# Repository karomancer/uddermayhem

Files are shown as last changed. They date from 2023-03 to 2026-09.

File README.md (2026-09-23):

# Udder Mayhem

A rhythm game you play by milking a cow. Squeeze the silicone udder in time with the music to fill coffee cups for the customers of a cow-run café.

Udder Mayhem started as the midterm for *The New Arcade* at NYU ITP in spring 2023, went on to the ITP Showcase and the Coney Island Maker Faire, and was written up in Make Magazine. The full story, with photos and videos, is on my portfolio: https://www.karinachowtime.com/portfolio/uddermayhem

## What's in this repo

| Folder | What it is |
|---|---|
| `teensy/` | Firmware for the udder controller. A Teensy reads four force-sensing resistors, one per teat, and shows up to the computer as a keyboard. |
| `CAD/` | Fusion 360 and STL files for the controller body and the silicone udder mold. |
| `MakeMagazine/` | Files that go with the Make Magazine article, including the one-piece mold box. |
| `BovineBaristaGame/` | The original Unity project from the 2023 class, under the game's working title. This is the hand-written version described in the portfolio write-up. |

## Playing it

**Play the current arcade build in your browser: https://karomancer.github.io/uddermayhem/**

The controller presses plain keyboard keys, so anything that runs the game works with either the udder or a keyboard:

| Teat | Key |
|---|---|
| Back left | Q |
| Back right | W |
| Front left | A |
| Front right | S |

Squeeze when a cup arrives under a teat and let go when it's full.

## The current game

The version people play at events today is a much bigger arcade build that runs on a Raspberry Pi inside the cabinet, made together with Kevin Mitchell. That's the build linked above, served from this repo's `gh-pages` branch. Its source isn't in this repo. The Unity project here is the 2023 class project, kept as the record of how it was built.

## Building the controller

Start with the Make Magazine files and the Teensy sketch. The sketch expects four FSRs on the analog pins named at the top of `teensy/fsr_udder/fsr_udder.ino`, and the press and release thresholds are constants there if your sensors read differently.

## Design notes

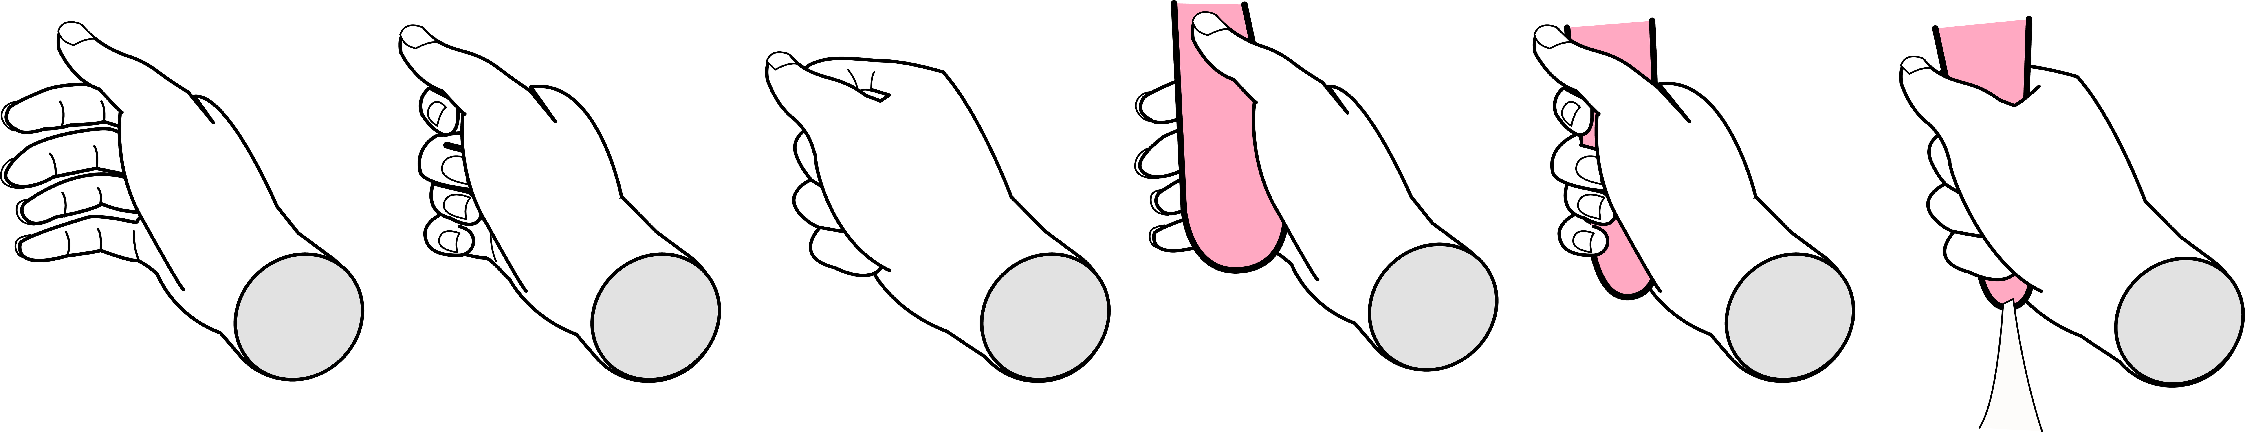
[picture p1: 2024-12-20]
BovineBaristaGame/Assets/Sprites/hands_spritemap@2x-8.png

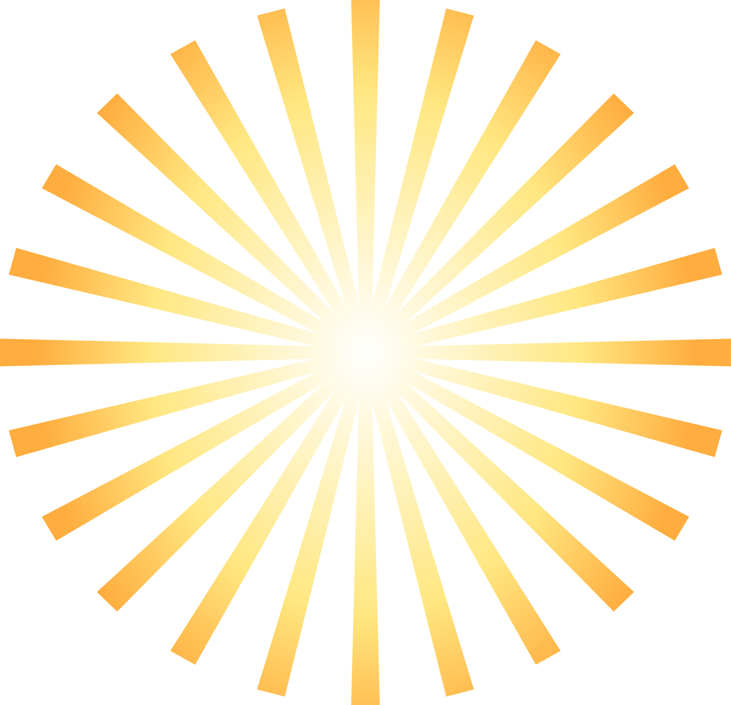
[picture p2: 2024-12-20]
BovineBaristaGame/Assets/Sprites/TitleScreen/2x/SunRays@2x-8.png

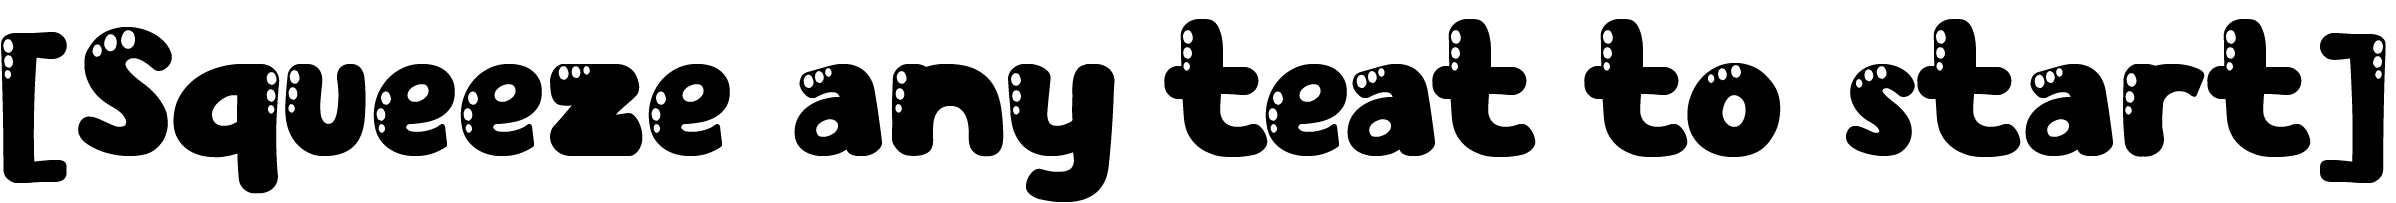
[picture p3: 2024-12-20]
BovineBaristaGame/Assets/Sprites/TitleScreen/2x/SqueezeMessage@2x-8.png

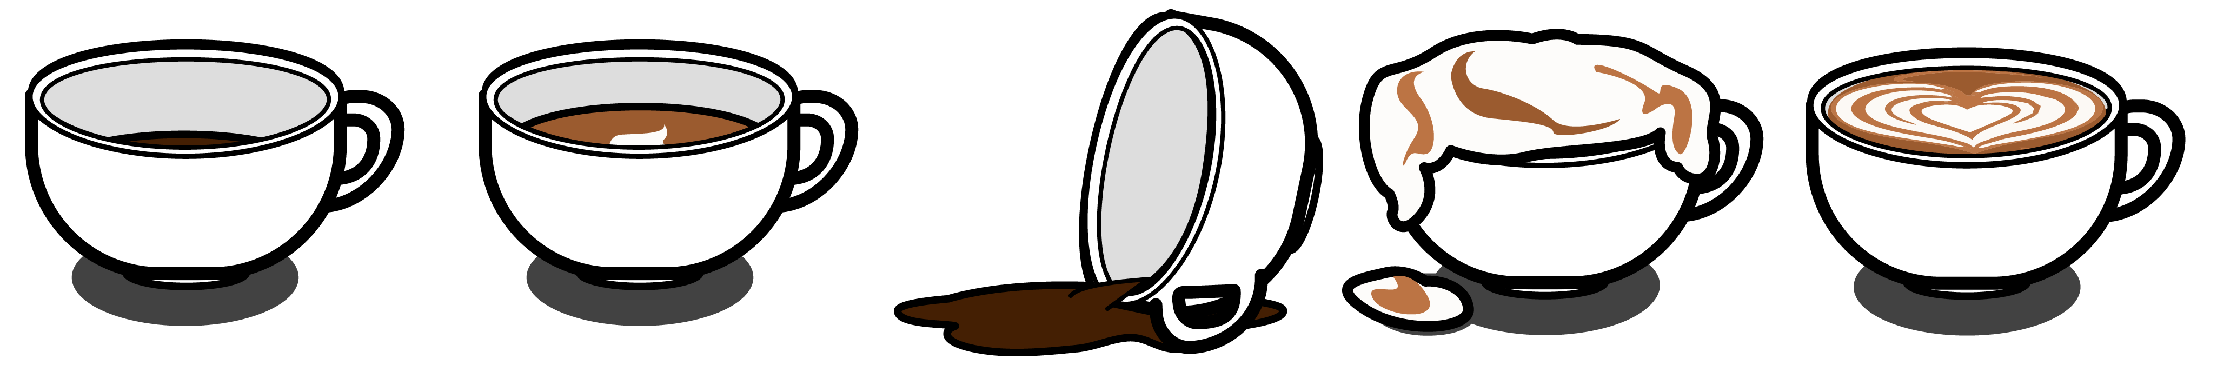
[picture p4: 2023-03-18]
BovineBaristaGame/Assets/Sprites/coffee_spritesheet.png

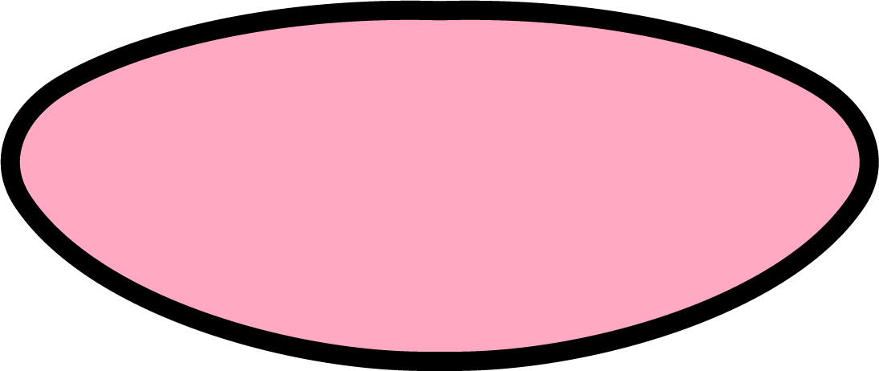
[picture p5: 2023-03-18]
BovineBaristaGame/Assets/Sprites/udderBase@2x.png

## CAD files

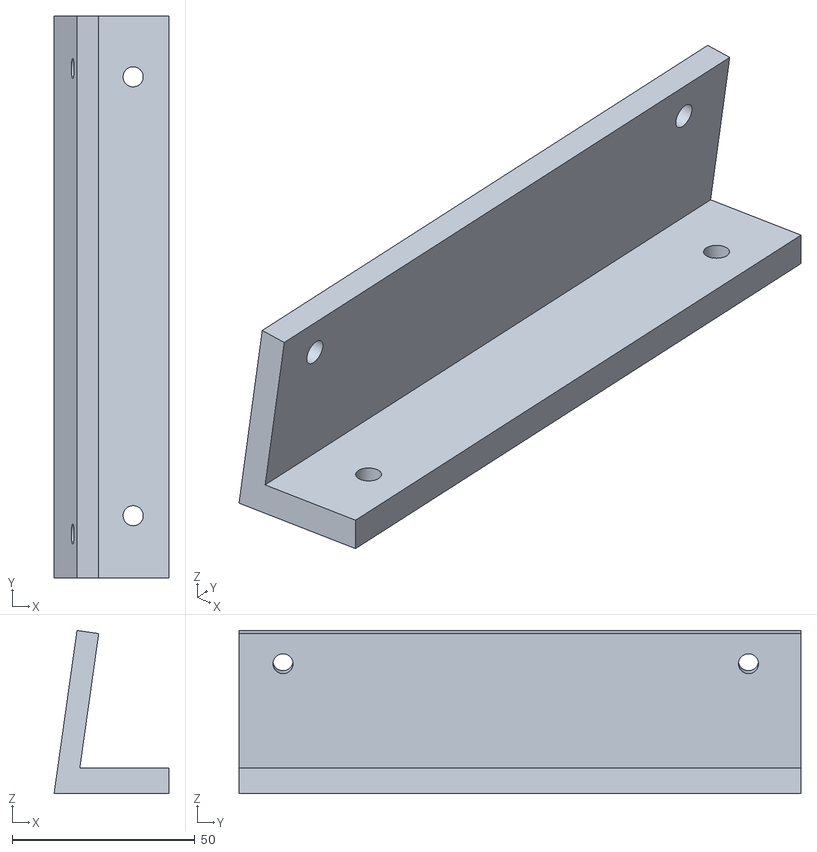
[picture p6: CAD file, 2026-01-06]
CAD/brackets/BackShelf.stl
31.4 x 153.6 x 44.6

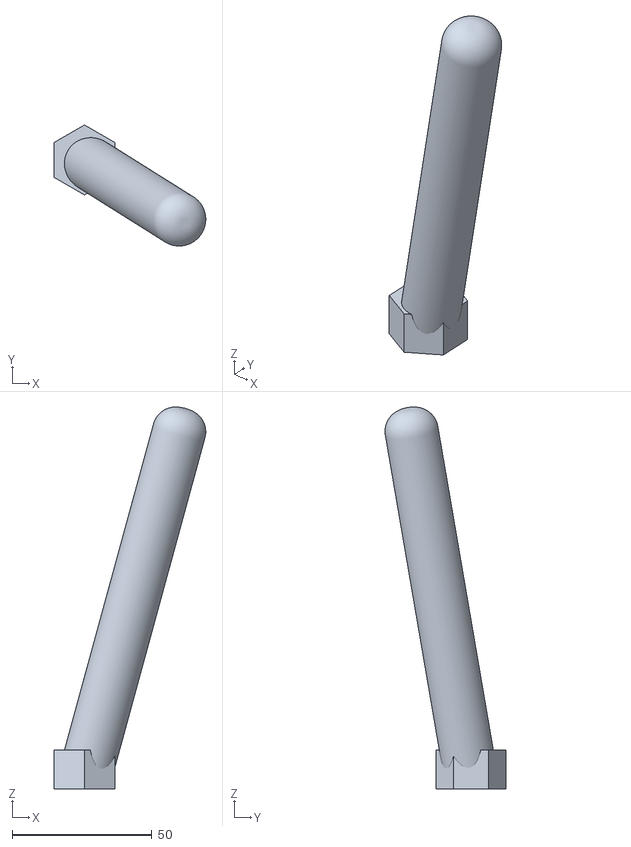
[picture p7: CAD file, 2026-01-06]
CAD/Pole2.stl
54.2 x 43.3 x 136.5

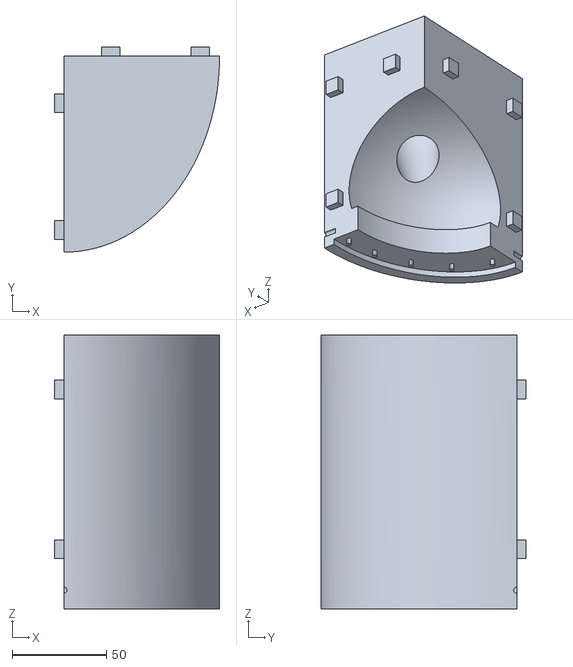
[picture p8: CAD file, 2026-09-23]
MakeMagazine/udder_moldbox_4pc_br_pegs.stl
87.8 x 109.2 x 145.7

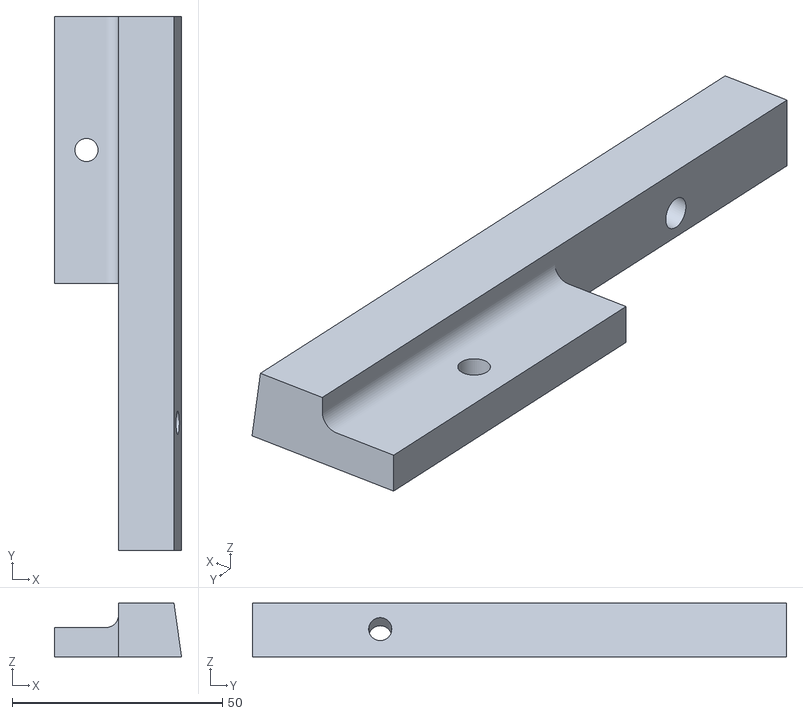
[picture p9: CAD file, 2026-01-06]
CAD/brackets/ScreenShelfBackBracket.stl
30.2 x 127.0 x 12.8

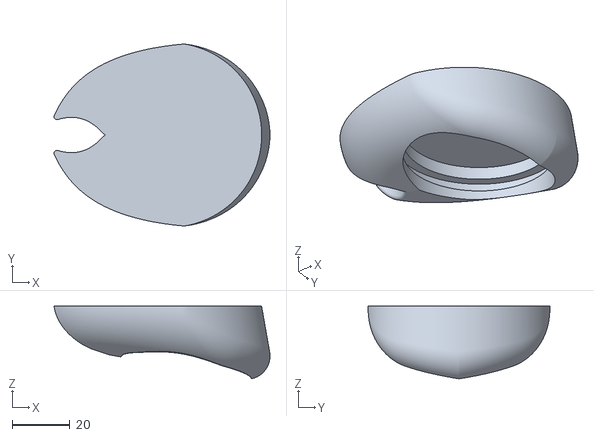
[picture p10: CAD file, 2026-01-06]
CAD/hoof.stl
74.7 x 62.9 x 25.1

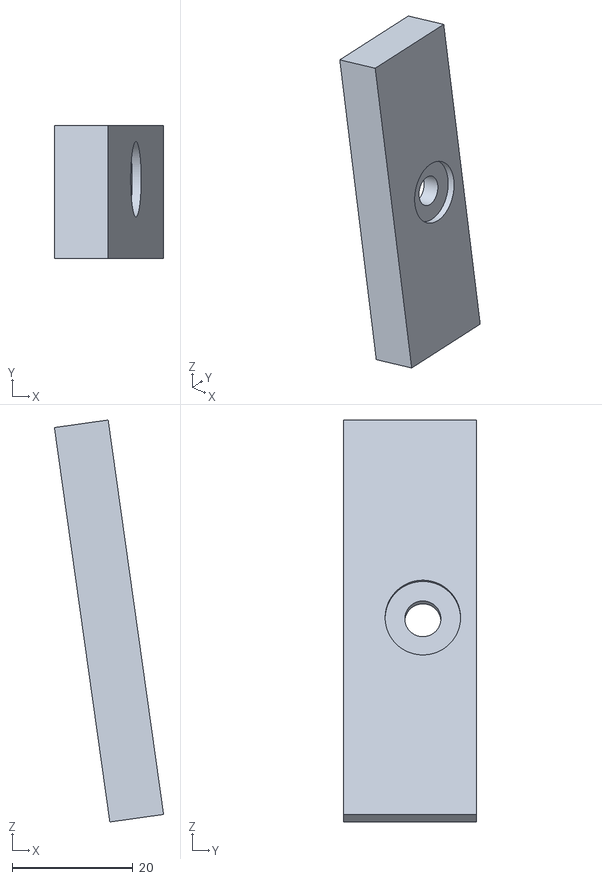
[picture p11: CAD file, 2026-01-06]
CAD/spacer.stl
18.1 x 22.1 x 66.6

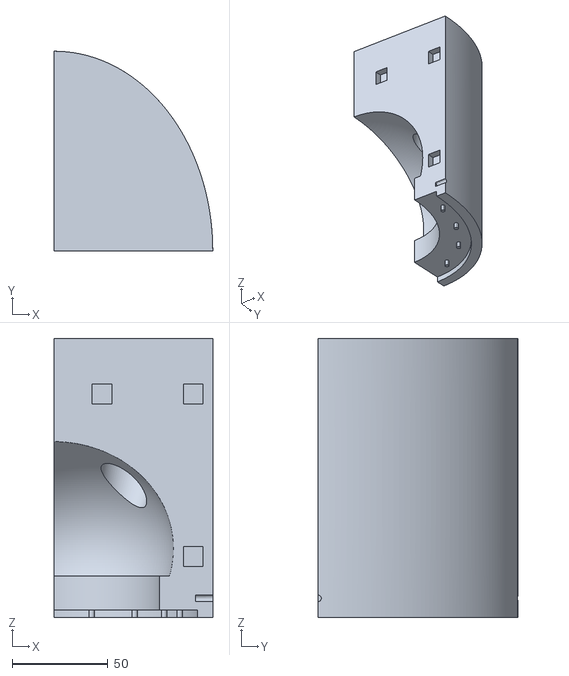
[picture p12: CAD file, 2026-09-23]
MakeMagazine/udder_moldbox_4pc_tr_sockets.stl
82.8 x 104.2 x 145.7

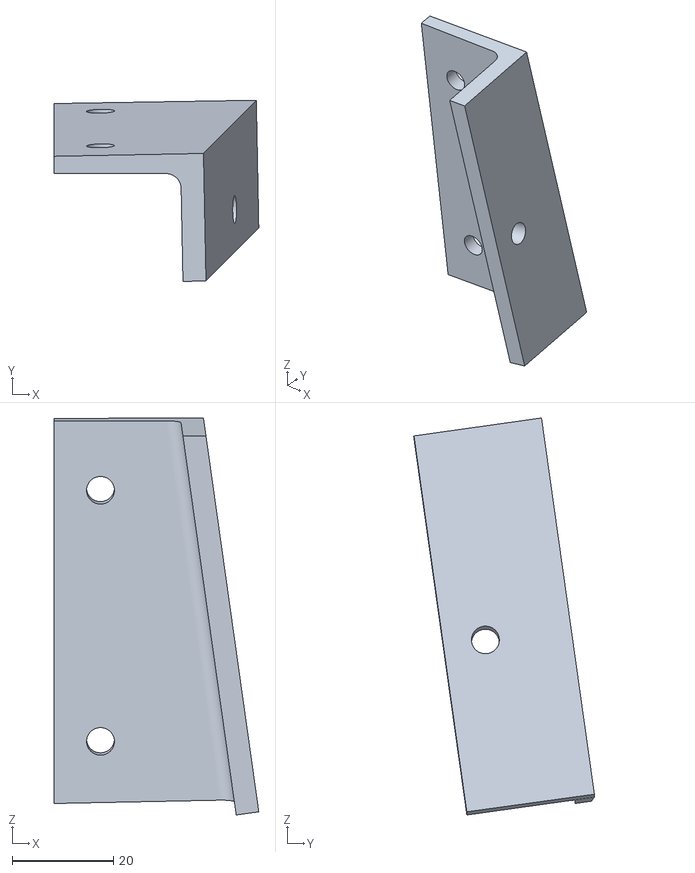
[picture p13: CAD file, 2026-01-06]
CAD/brackets/ButtBracketLeft.stl
40.4 x 35.7 x 78.3

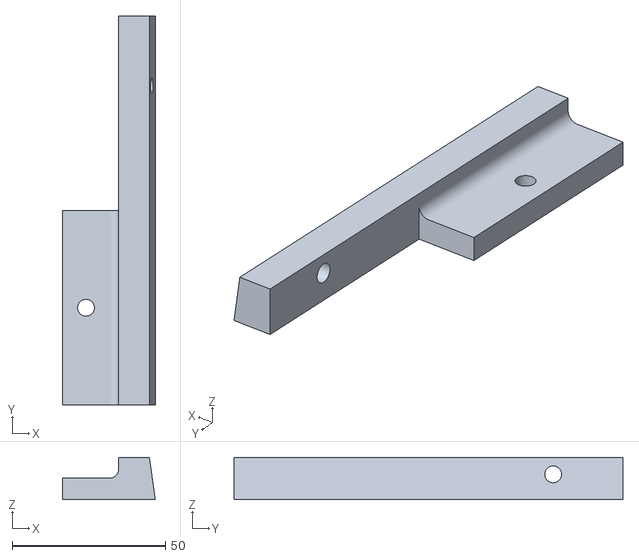
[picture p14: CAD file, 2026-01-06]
CAD/brackets/ScreenShelfBackBracketRight.stl
30.2 x 127.0 x 13.8

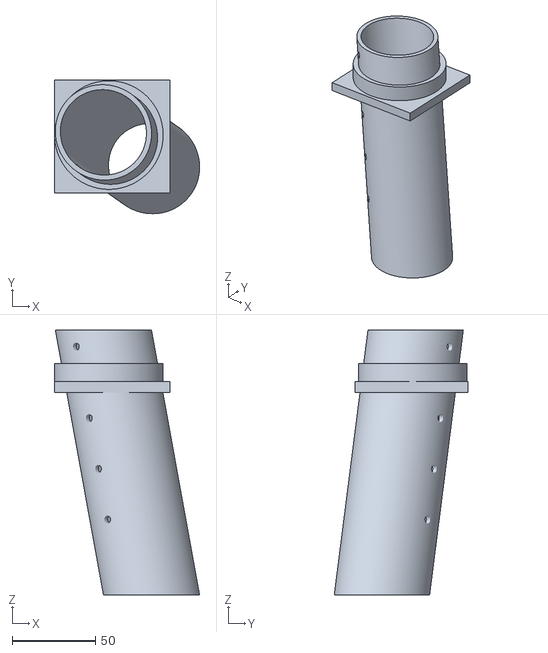
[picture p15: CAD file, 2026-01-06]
CAD/LEG2.stl
87.2 x 80.1 x 159.0

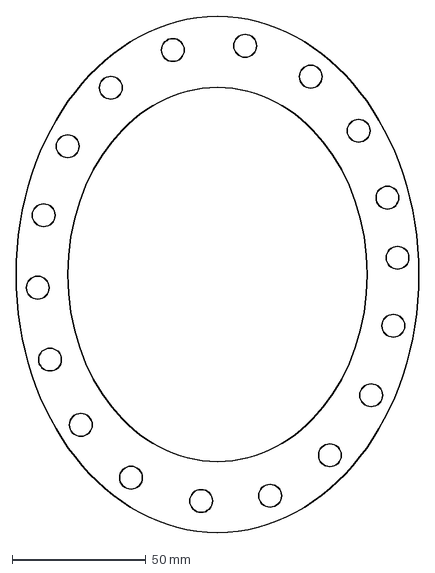
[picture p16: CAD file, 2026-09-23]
MakeMagazine/udder_baseboard_cutout.dxf
150.7 x 193.1 mm

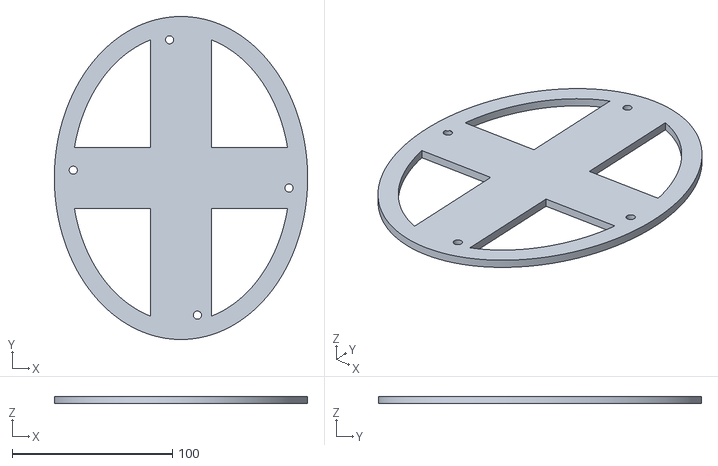
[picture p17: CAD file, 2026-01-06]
CAD/Brace3.stl
158.0 x 201.4 x 4.50

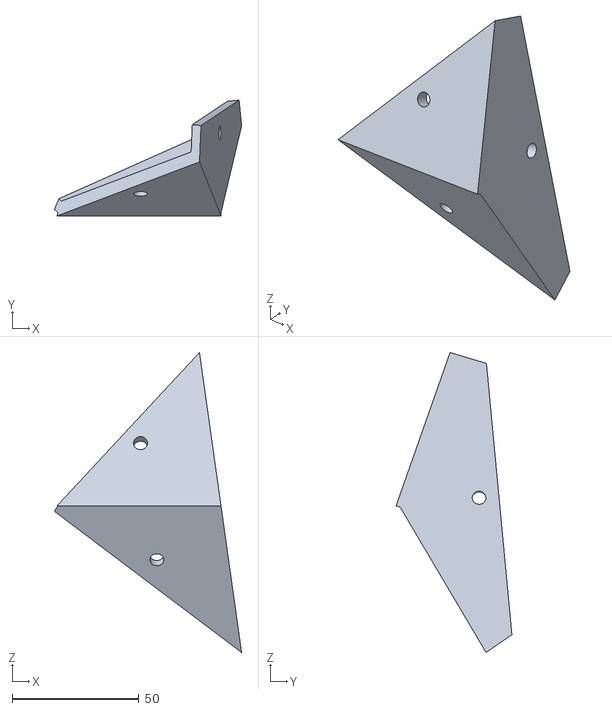
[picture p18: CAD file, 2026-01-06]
CAD/brackets/LeftNeckBracket.stl
73.9 x 45.7 x 118.3

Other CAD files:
CAD/bambu_fullbox.gcode.3mf
CAD/full_udder.stl
MakeMagazine/udder_moldbox_4pc_tl_pegs.stl
CAD/brackets/ScreenShelfFrontBracket.stl
MakeMagazine/udder_moldbox_4pc_bl_sockets.stl
CAD/Brace.stl
CAD/Brace1.stl
CAD/Brace2.stl
CAD/InnerUdder.stl
CAD/LEG1.stl
CAD/LEG3.stl
CAD/LEG4.stl
CAD/NewBrace.stl
CAD/NewBrace2Holes.stl
CAD/Pole1.stl
CAD/Pole3.stl
CAD/Pole4.stl
CAD/ScreenShelfBackBracket.stl
CAD/UdderSingularMoldBox.3mf
CAD/UdderSingularMoldBox.stl
CAD/brackets/BellyShelf.stl
CAD/brackets/ButtBracketRight.stl
CAD/brackets/ButtShelf.stl
CAD/brackets/ContainerInsert.stl
CAD/brackets/RightButtBracket.stl
CAD/brackets/RightNeckBracket.stl
CAD/brackets/ScreenShelfBackBracketLeft.stl
CAD/dairyana_grande_no_fingers.f3d
CAD/leg_holder.stl
CAD/leggo.stl
CAD/silicone_top.dxf
CAD/top_spacer.stl
MakeMagazine/udder_inset.stl
MakeMagazine/udder_inset_pole.stl
MakeMagazine/udder_moldbox_1pc.stl
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

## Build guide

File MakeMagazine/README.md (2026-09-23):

# Make Magazine files

Files for the Make Magazine article on building the silicone udder controller. The article covers the udder itself, not the cow-shaped cabinet around it.

## Files

Click a picture or file name to open it on GitHub, where you can spin the model around and download it.

| Preview | File | What it is | Print or cut |
|---|---|---|---|
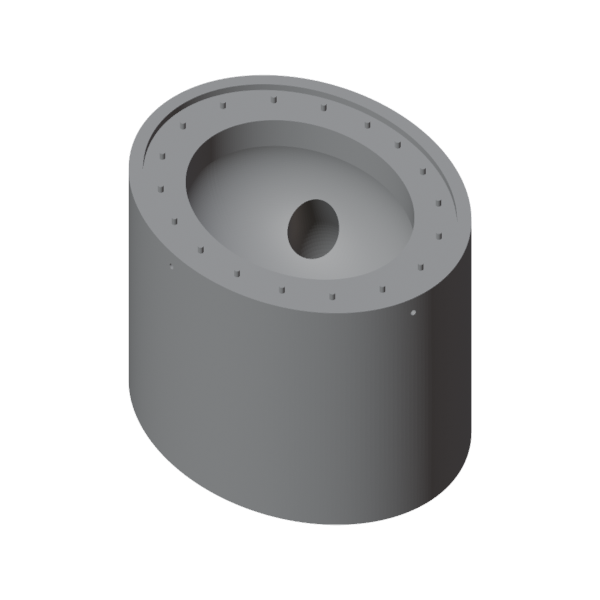
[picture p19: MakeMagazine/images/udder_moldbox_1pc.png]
One-piece mold box
|  | [`udder_moldbox_1pc.stl`](udder_moldbox_1pc.stl) | One-piece mold box for casting the silicone. Needs a print bed of at least 166 × 209 × 146 mm. | 1 |
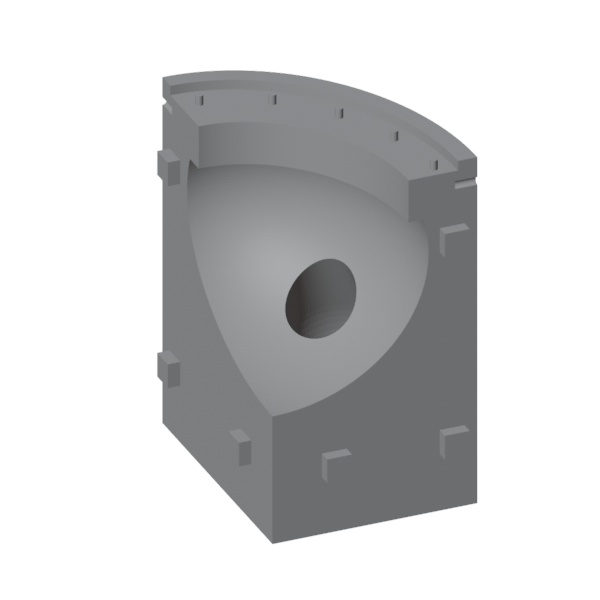
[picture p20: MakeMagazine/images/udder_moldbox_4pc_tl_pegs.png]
Four-part mold box, top-left quadrant with pegs
|  | [`udder_moldbox_4pc_tl_pegs.stl`](udder_moldbox_4pc_tl_pegs.stl) | Top-left quadrant of the four-part mold box, with pegs. About 83 × 104 × 146 mm. | 1 |
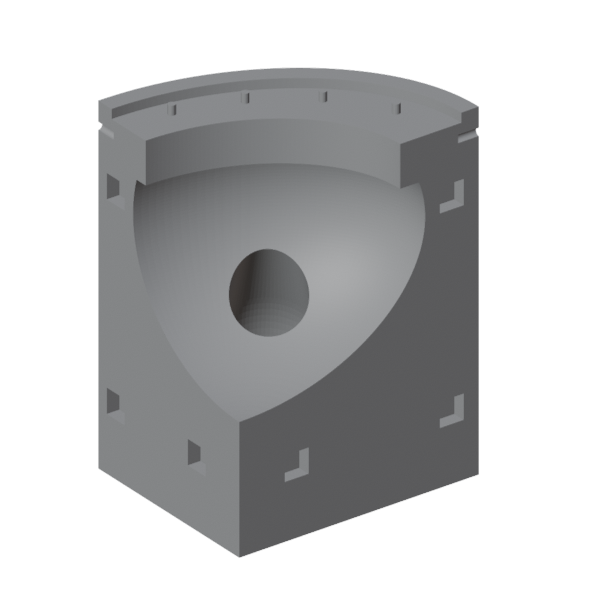
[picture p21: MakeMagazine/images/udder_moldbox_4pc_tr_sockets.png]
Four-part mold box, top-right quadrant with sockets
|  | [`udder_moldbox_4pc_tr_sockets.stl`](udder_moldbox_4pc_tr_sockets.stl) | Top-right quadrant, with sockets. | 1 |
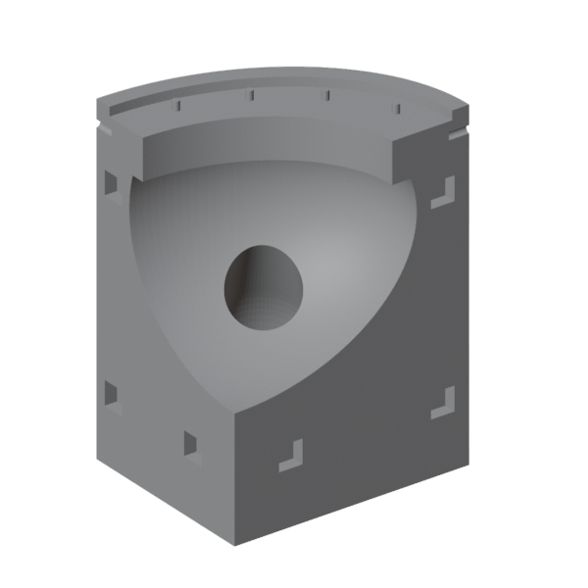
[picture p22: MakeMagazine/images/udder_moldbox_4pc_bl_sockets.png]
Four-part mold box, bottom-left quadrant with sockets
|  | [`udder_moldbox_4pc_bl_sockets.stl`](udder_moldbox_4pc_bl_sockets.stl) | Bottom-left quadrant, with sockets. | 1 |
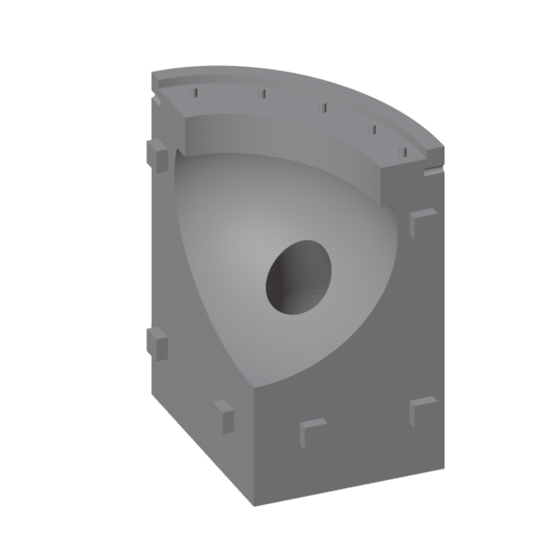
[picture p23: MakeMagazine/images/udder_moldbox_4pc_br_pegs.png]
Four-part mold box, bottom-right quadrant with pegs
|  | [`udder_moldbox_4pc_br_pegs.stl`](udder_moldbox_4pc_br_pegs.stl) | Bottom-right quadrant, with pegs. | 1 |
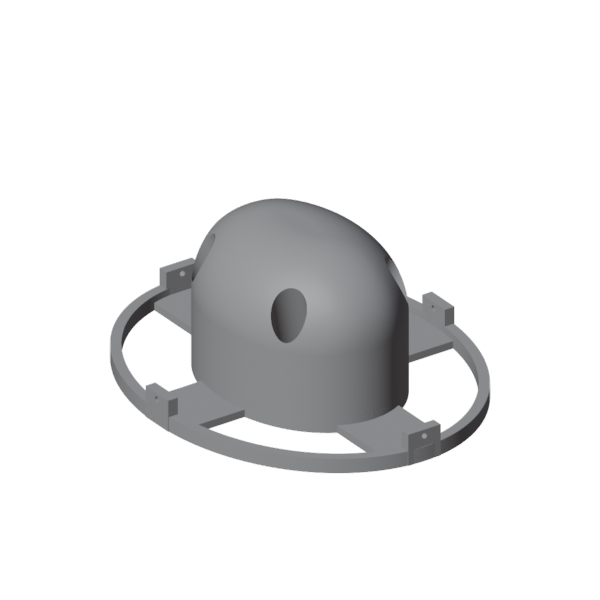
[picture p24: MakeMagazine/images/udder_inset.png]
Mold insert
|  | [`udder_inset.stl`](udder_inset.stl) | Insert that sits in the mold box and forms the inside of the udder. | 1 |
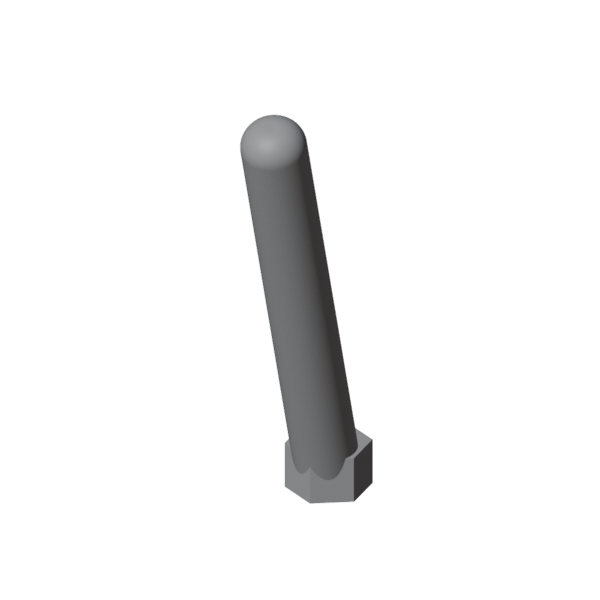
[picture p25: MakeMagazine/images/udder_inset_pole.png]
Teat pole
|  | [`udder_inset_pole.stl`](udder_inset_pole.stl) | Pole that forms the hollow inside each teat. | 4 |
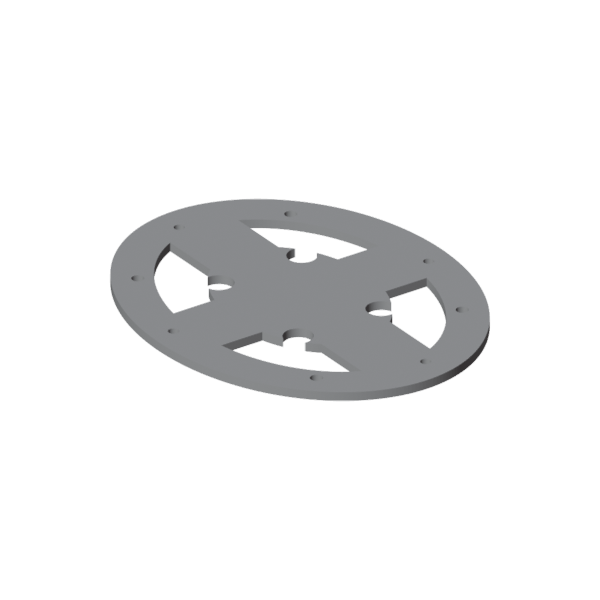
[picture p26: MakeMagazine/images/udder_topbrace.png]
Top brace
|  | [`udder_topbrace.stl`](udder_topbrace.stl) | Optional brace that holds in the expanding foam and helps when mounting the udder. | 1 |
| <a href="udder_baseboard_cutout.dxf">Baseboard cutout template</a> | [`udder_baseboard_cutout.dxf`](udder_baseboard_cutout.dxf) | Cutting template for the board the udder mounts to. Units are millimeters. | 1 |
| | [`fsrTeatTest/fsrTeatTest.ino`](fsrTeatTest/fsrTeatTest.ino) | Sketch for testing the four FSRs before and after casting the foam. | — |

Print the four-part mold even if you cast the silicone in the one-piece mold. The foam is cast in the four-part mold, since the finished udder can't come back out of the one-piece one.

The four-part mold is the one-piece mold cut along its center lines, so each quadrant holds one whole teat. The top-left and bottom-right quadrants have three 10 mm square pegs on each cut face, and the other two have matching sockets with 0.2 mm of clearance per side. Each quadrant is different, so print one of each and match pegs to sockets when you assemble it.

## Printing

The molds aren't functional parts, so print them fine and hollow: about 0.16 mm layers for a smooth cast and about 5% infill.

The insert screws to the mold box with 4 × M3x10 screws so it can't float up while the silicone cures.

## Mounting template

`udder_baseboard_cutout.dxf` has two ellipses and 18 holes:

- **Inner ellipse (111.9 × 140.0 mm):** cut this out. The udder hangs through it.
- **Outer ellipse (150.7 × 193.1 mm):** don't cut. It marks where the silicone lip ends, so you can see how much board the udder covers.
- **18 holes (8.56 mm):** for threaded inserts that take the 18 × M6x8 screws.

The template assumes a 3/4" board. The original is cut from MDF.

## Testing the FSRs

`fsrTeatTest.ino` reads four FSRs on A0–A3 and prints each reading to the serial monitor at 9600 baud, labeled by jumper wire color (white, green, yellow, orange). Wire one lead of each FSR to 3.3V and the other to its analog pin, with a pull-down resistor from the pin to ground. The article uses 5.1kΩ; anything from 4.7kΩ to 22kΩ works.

Readings go up as you squeeze. Uncomment the check at the bottom of `loop()` and adjust `THRESHOLD` until a squeeze prints `White PRESSED!` and resting doesn't. Copy the check for the other three colors.

## Using it as a game controller

Once the readings look right, flash [`teensy/fsr_udder/fsr_udder.ino`](../teensy/fsr_udder/fsr_udder.ino). It turns each teat into a keyboard key, so the udder works with anything that takes keyboard input.

**Try it out by playing Udder Mayhem in your browser: https://karomancer.github.io/uddermayhem/**

In the Arduino IDE with Teensyduino, set **Tools → USB Type** to **Keyboard** (or any option that includes Keyboard) before uploading. The sketch won't compile without it.

| Teat | Pin | Key |
|---|---|---|
| Front left | A0 | A |
| Back right | A1 | W |
| Front right | A2 | S |
| Back left | A3 | Q |

`THRESHOLD` (900) is the one value to tune. If a teat never registers, lower it. If it fires without being squeezed, raise it.

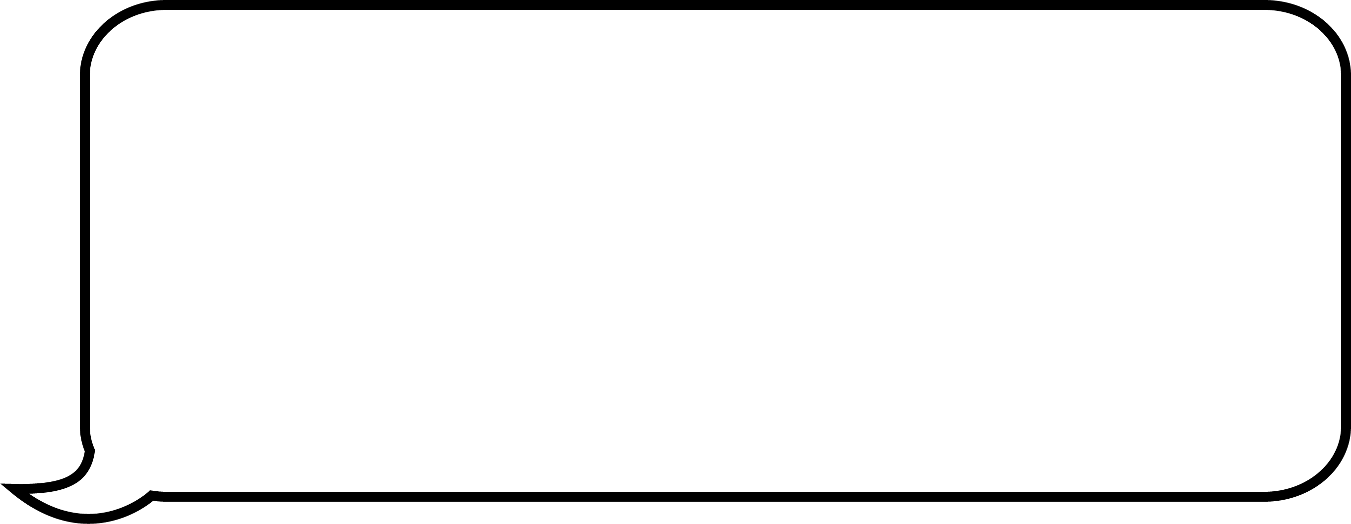
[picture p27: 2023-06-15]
BovineBaristaGame/Assets/Sprites/tutorialSpeechBubble@2x-8.png

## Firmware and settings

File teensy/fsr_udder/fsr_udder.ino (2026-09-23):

// A0 = 17, A3 = 21
const byte FRONT_RIGHT_TEAT = A2; 
const byte FRONT_LEFT_TEAT = A0;
const byte BACK_LEFT_TEAT = A3;
const byte BACK_RIGHT_TEAT = A1;

const int THRESHOLD = 900;
const int DEBOUNCE_DELAY = 50; // milliseconds

bool isFrontLeftSqueezed = false;
bool isFrontRightSqueezed = false;
bool isBackLeftSqueezed = false;
bool isBackRightSqueezed = false;

unsigned long frontLeftDebounceTime = 0;
unsigned long frontRightDebounceTime = 0;
unsigned long backLeftDebounceTime = 0;
unsigned long backRightDebounceTime = 0;

void setup() {
  pinMode(FRONT_LEFT_TEAT, INPUT);
  pinMode(FRONT_RIGHT_TEAT, INPUT);
  pinMode(BACK_LEFT_TEAT, INPUT);
  pinMode(BACK_RIGHT_TEAT, INPUT);
  Serial.begin(9600);
}

void checkForFrontLeft() {
  int value = analogRead(FRONT_LEFT_TEAT);
  if (millis() - frontLeftDebounceTime > DEBOUNCE_DELAY) {
    bool currentState = (value > THRESHOLD);
    if (currentState != isFrontLeftSqueezed) {
      isFrontLeftSqueezed = currentState;
      if (isFrontLeftSqueezed) {
        Serial.println("Front Left Teat pressed!");
        Keyboard.press(KEY_A);
      } else {
        Serial.println("Front Left Teat released!");
        Keyboard.release(KEY_A);
      }
      frontLeftDebounceTime = millis();
    }
  }
}

void checkForFrontRight() {
  int value = analogRead(FRONT_RIGHT_TEAT);
  if (millis() - frontRightDebounceTime > DEBOUNCE_DELAY) {
    bool currentState = (value > THRESHOLD);
    if (currentState != isFrontRightSqueezed) {
      isFrontRightSqueezed = currentState;
      if (isFrontRightSqueezed) {
        Serial.println("Front Right Teat pressed!");
        Keyboard.press(KEY_S);
      } else {
        Serial.println("Front Right Teat released!");
        Keyboard.release(KEY_S);
      }
      frontRightDebounceTime = millis();
    }
  }
}

void checkForBackLeft() {
  int value = analogRead(BACK_LEFT_TEAT);
  if (millis() - backLeftDebounceTime > DEBOUNCE_DELAY) {
    bool currentState = (value > THRESHOLD);
    if (currentState != isBackLeftSqueezed) {
      isBackLeftSqueezed = currentState;
      if (isBackLeftSqueezed) {
        Serial.println("Back Left Teat pressed!");
        Keyboard.press(KEY_Q);
      } else {
        Serial.println("Back Left Teat released!");
        Keyboard.release(KEY_Q);
      }
      backLeftDebounceTime = millis();
    }
  }
}

void checkForBackRight() {
  int value = analogRead(BACK_RIGHT_TEAT);
  if (millis() - backRightDebounceTime > DEBOUNCE_DELAY) {
    bool currentState = (value > THRESHOLD);
    if (currentState != isBackRightSqueezed) {
      isBackRightSqueezed = currentState;
      if (isBackRightSqueezed) {
        Serial.println("Back Right Teat pressed!");
        Keyboard.press(KEY_W);
      } else {
        Serial.println("Back Right Teat released!");
        Keyboard.release(KEY_W);
      }
      backRightDebounceTime = millis();
    }
  }
}

void loop() {
  checkForFrontLeft();
  checkForFrontRight();
  checkForBackLeft();
  checkForBackRight();
  delay(10);
}

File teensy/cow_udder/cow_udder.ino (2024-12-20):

const int FrontLeftTeat = A3;
const int FrontRightTeat = A2;
const int BackLeftTeat = A1;
const int BackRightTeat = A0;


// The larger the number, the more sensitive it is
const int FRONT_LEFT_RELEASE_THRESHOLD = 30;
const int FRONT_RIGHT_RELEASE_THRESHOLD = 26;
const int BACK_LEFT_RELEASE_THRESHOLD = 36;
const int BACK_RIGHT_RELEASE_THRESHOLD = 29;

// The larger the number, the harder you have to squeezes
const int FRONT_LEFT_PRESS_THRESHOLD = 1010;
const int FRONT_RIGHT_PRESS_THRESHOLD = 1025;
const int BACK_LEFT_PRESS_THRESHOLD = 990;
const int BACK_RIGHT_PRESS_THRESHOLD = 1020;

bool isFrontLeftSqueezed = false;
bool isFrontRightSqueezed = false;
bool isBackLeftSqueezed = false;
bool isBackRightSqueezed = false;

void setup() {
  pinMode(FrontLeftTeat, INPUT);
  pinMode(FrontRightTeat, INPUT);
  pinMode(BackLeftTeat, INPUT);
  pinMode(BackRightTeat, INPUT);
  Serial.begin(9600);
}

void checkForFrontLeft() {
  int frontLeftValue = analogRead(FrontLeftTeat);
    // Serial.println(frontLeftValue);
  if (frontLeftValue > FRONT_LEFT_PRESS_THRESHOLD && !isFrontLeftSqueezed) {
    Serial.println("Front Left Teat pressed!");
    Keyboard.press(KEY_A);
    isFrontLeftSqueezed = true;
  } else if (isFrontLeftSqueezed && frontLeftValue < FRONT_LEFT_RELEASE_THRESHOLD) {
    Serial.println("Front left teat released!");
    Keyboard.release(KEY_A);
    isFrontLeftSqueezed = false;
  }
}

void checkForFrontRight() {
  int frontRightValue = analogRead(FrontRightTeat);
  if (frontRightValue > FRONT_RIGHT_PRESS_THRESHOLD && !isFrontRightSqueezed) {
    Serial.println("Front Right Teat pressed!");
    Keyboard.press(KEY_S);
    isFrontRightSqueezed = true;
  } else if (isFrontRightSqueezed && frontRightValue < FRONT_RIGHT_RELEASE_THRESHOLD) {
    Serial.println("Front Right teat released!");
    Keyboard.release(KEY_S);
    isFrontRightSqueezed = false;
  }
}

void checkForBackLeft() {
  int backLeftValue = analogRead(BackLeftTeat);
  if (backLeftValue > BACK_LEFT_PRESS_THRESHOLD && !isBackLeftSqueezed) {
    Serial.println("Back Left Teat pressed!");
    Keyboard.press(KEY_Q);
    isBackLeftSqueezed = true;
  } else if (isBackLeftSqueezed && backLeftValue < BACK_LEFT_RELEASE_THRESHOLD) {
    Serial.println("Back Left Teat released!");
    Keyboard.release(KEY_Q);
    isBackLeftSqueezed = false;
  }
}

void checkForBackRight() {
  int backRightValue = analogRead(BackRightTeat);
  if (backRightValue > BACK_RIGHT_PRESS_THRESHOLD && !isBackRightSqueezed) {
    Serial.println("Back Right Teat pressed!");
    Keyboard.press(KEY_W);
    isBackRightSqueezed = true;
  } else if (isBackRightSqueezed && backRightValue < BACK_RIGHT_RELEASE_THRESHOLD) {
    Serial.println("Back Right teat released!");
    Keyboard.release(KEY_W);
    isBackRightSqueezed = false;
  }
}
 
void loop() {
  checkForFrontLeft();
  checkForFrontRight();
  checkForBackLeft();
  checkForBackRight();
  delay(10);
}

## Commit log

2023-03-18 Add working prototype
    - STL files perhaps to come later
2023-05-14 Add teensy code
2024-12-20 Simplified tutorial fix + new intro animation and song
    * Expanded tutorial WIP (errors)
    * A little buggy
    * Delete a lot of example code, add in clouds
    * Add text reqs, add in logo and rays
    * Got clouds working
    * Finished title animations for now!
    * Add udderjangle to title screen
    [cow_udder.ino]
2026-01-06 Add cabinet CAD files
    [BackShelf.stl, BellyShelf.stl, Brace.stl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]
2026-09-23 Add Make Magazine files, CAD, and current controller firmware
    [udder_inset.stl, udder_inset_pole.stl, udder_moldbox_1pc.stl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]
2026-09-23 Add Make Magazine mold quadrants, baseboard template, and README
    [udder_baseboard_cutout.dxf, udder_moldbox_4pc_q1q3.stl, udder_moldbox_4pc_q2q4.stl]
2026-09-23 Add STL preview thumbnails to Make Magazine README
2026-09-23 Replace four-part mold with pegged and socketed quadrants cut from the one-piece box
    [udder_moldbox_4pc_bl_sockets.stl, udder_moldbox_4pc_br_pegs.stl, udder_moldbox_4pc_q1q3.stl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]
